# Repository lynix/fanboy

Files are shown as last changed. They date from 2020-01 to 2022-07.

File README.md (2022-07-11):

# FanBoy FanBoy Logo

Open Source PWM Fan Controller




## Summary

*FanBoy* is an Open Source DIY approach to providing a cross-platform PWM fan
controller with temperature sensor support that can easily be modified to fit
your needs.

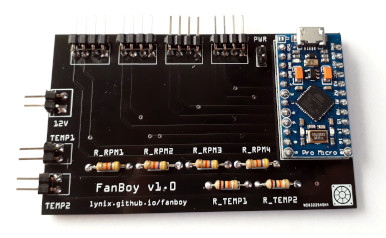
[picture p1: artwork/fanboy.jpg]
FanBoy


## Features

* **Four discrete PWM channels**  
    Supports multiple fans per channel (up to 40&thinsp;W max. total power
    draw), auto-detection for disconnected fans and RPM sensing
* **Two temperature sensor inputs**  
    Supports standard 10&thinsp;k&Omega; thermistors
* **Based on well-known Arduino platform**  
    Uses the ATmega32U4 of an Arduino Leonardo as MCU for minimal development
    overhead
* **Multiple operation modes per channel**  
    including *fixed duty*, *linear* and *target temperature*
    <sup>1</sup>
* **Persistent data storage**  
    Stores all settings as well as last operation mode CRC-protected in EEPROM
* **Simple serial protocol**  
    Comes with a simple static library for communication abstraction as well
    as a command line utility for configuration

<sup>1</sup> Planned but not implemented yet

## Components

This DIY kit consists of multiple components that are reflected as
subdirectories:

| Folder | Description | Platforms |
|:---|:---| :--- |
| [pcb](https://github.com/lynix/fanboy/tree/master/pcb) | PCB that can be manufactured very cheap via common PCB fabrication services | Linux, Win32, Mac |
| [firmware](https://github.com/lynix/fanboy/tree/master/firmware) | Firmware based on *Arduino* Core | Linux, Win32, Mac |
| [libfanboy](https://github.com/lynix/fanboy/tree/master/libfanboy) | Static C library that implements serial interface between host and *FanBoy* | Linux, Win32, Mac |
| [enclosure](https://github.com/lynix/fanboy/tree/master/enclosure) | Simple 3D printable enclosure that fits a 2.5" drive slot | - |
| [fanboycli](https://github.com/lynix/fanboy/tree/master/fanboycli) | Command line client based on `libfanboy` | Linux, Win32, Mac |

:information_source: In addition to these components there is a Qt based GUI
called [FanMan](https://github.com/lynix/fanman).

## Contributing

### Code

The code uses 4-space indentation and K&R style bracing. Usage of Arduino
libraries is kept low to keep the possibility of switching to avr-libc. Code
documentation is done inline (headers) using [Doxygen](http://www.doxygen.nl).

### Bugs / Features

Pull requests are always welcome. Feel free to report bugs or post questions
using the *issues* function on GitHub.

## License

This project is published under the terms of the *MIT License*. See the file
`LICENSE` for more information.

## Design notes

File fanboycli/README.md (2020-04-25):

# FanBoy FanBoy Logo

Open Source PWM Fan Controller




## Component: fanboycli

*fanboycli* is a command line interface application for *FanBoy* written in C
that makes use of *libfanboy*.

### Building

*fanboycli* uses [CMake](https://cmake.org) to provide a uniform cross-platform
build.

In order to build it separately (example on Linux):

```
$ cd fanboycli
$ cmake .
$ make
```

### Usage

The executable understands the following arguments:

| Argument  | Description |
|:---|:---|
| `-s` | Show current fan / sensor readings |
| `-c` | Show current configuration |
| `-f FAN`  | Select fan to control (1-4) |
| `-d DUTY` | Set selected fan to fixed duty (0-100) |
| `-m MODE` | Set fan control mode (*manual* or *linear*) |
| `-M TEMP` | Set mapped sensor no. (1-2) |
| `-l PARA` | Set linear control parameters (format see below) |
| `-L` | Load configuration from EEPROM |
| `-S` | Save current configuration to EEPROM |
| `-C` | Generate fan curves as CSV samples (duty vs. RPM) |
| `-R` | Reset FanBoy (re-initializes USB as well) |
| `-D DEV`  | Set serial interface (default value depends on platform) |
| `-V` | Show FanBoy firmware version and build timestamp |
| `-h` | Show usage help text |

Note that some argument(s) may be repeated for combination (see below).

#### Examples

Show current readings:

```
$ fanboycli -s
```

Set Fan 1 to 25% fixed duty, Fan 2 to 50% and make changes permanent:

```
$ fanboycli -f 1 -d 25 -f 2 -d 50 -S
```

Set Fan 3 to linear fan control with given parameters:

```
$ fanboycli -f 3 -l 20:19.5:80:40.5
```

### Linear Fan Control

Linear fan control makes the fan duty follow a linear curve between a given
minimum and maximum value.

Parameter format for `-l` argument: `LOW_DUTY:LOW_TEMP:HIGH_DUTY:HIGH_TEMP`

* `LOW_TEMP`: Low temperature
* `HIGH_TEMP`: High temperature
* `LOW_DUTY`: Fan duty applied when temperature <= `TEMP_LOW`
* `HIGH_DUTY`: Fan duty applied when temperature >= `TEMP_HIGH`

## License

This project is published under the terms of the *MIT License*. See the file
`LICENSE` for more information.

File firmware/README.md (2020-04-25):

# FanBoy FanBoy Logo

Open Source PWM Fan Controller




## Component: Firmware

The firmware is based on the official Arduino core. Previous attempts of using
[avr-libc](https://www.nongnu.org/avr-libc) turned out to require too much
effort as the ATmega32U4 requires a USB stack for its serial interface.
[LUFA](https://github.com/Palatis/Arduino-Lufa) may be a solution to this and
shall be evaluated.

### Building

The firmware can either be built and uploaded using the official *Arduino* IDE
or using the provided Makefile that is based on
[Arduino-Makefile](https://github.com/sudar/Arduino-Makefile).

In case of the latter, make sure you have the following installed (package names
may vary between distros): `arduino`, `arduino-mk`

The firmware can be built and uploaded as follows:

```
$ cd firmware
$ make
$ make upload
```

## License

This project is published under the terms of the *MIT License*. See the file
`LICENSE` for more information.

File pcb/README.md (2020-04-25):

# FanBoy FanBoy Logo

Open Source PWM Fan Controller




## Component: PCB

*FanBoy*'s core is the *Micro* version of an *Arduino Leonardo* (e.g.
*Paradisetronic Pro Micro* or *SparkFun Pro Micro*) carried by a very simple
PCB:

FanBoy

The board has been designed using [Fritzing](https://fritzing.org) and can be
manufactured easily via common PCB fabrication services.

**Note:** The Fritzing file makes use of the 'SparkFun Pro Micro' part created
by [Hauke Thorenz](https://github.com/htho/fritzing-parts).

### Board Description

| Connector | Description |
|:--- |:--- |
| `12V` | 12&thinsp;V DC input |
| `TEMP1`, `TEMP2` | Temperature sensor connectors |
| `FAN1-4` | PWM fan connectors |
| `R_RPM1-4` | Pull-up resistors for fan RPM signal (4.7&thinsp;k&Omega;) |
| `R_TEMP1`, `R_TEMP2` | Thermistor reference resistors (10&thinsp;k&Omega;) |
| `PWR` | Arduino power supply selector (open: USB, shorted: 12&thinsp;V DC) |

:warning: **Warning:** When using cheap *Pro Micro* clones like the ones from
Paradisetronic make sure that solder bridge `J1` is closed! You otherwise risk
frying the Arduino when connecting USB and 12V at the same time!

### Parts list

In order to build your own *FanBoy* you need the following:

* Arduino Leonardo, Micro version
* *FanBoy* PCB
* 4x 4.7&thinsp;k&Omega; resistors
* 2x 10&thinsp;k&Omega; resistors
* 4x KF2510 3+1pin fan headers
* 2x 2.54&thinsp;mm 2pin thermistor headers
* 2x 2.54&thinsp;mm 12pin headers for Arduino
* 1x 3.5&thinsp;mm DC 2pin header

## License

This project is published under the terms of the *MIT License*. See the file
`LICENSE` for more information.

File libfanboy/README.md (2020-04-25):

# FanBoy FanBoy Logo

Open Source PWM Fan Controller




## Component: libfanboy

*libfanboy* is a static library written in C that provides a cross-platform
abstraction of the binary serial protocol between *FanBoy* and host.

### Building

*libfanboy* uses [CMake](https://cmake.org) to provide a uniform cross-platform
build that can be integrated in other projects.

In order to build it separately (example on Linux):

```
$ cd libfanboy
$ cmake .
$ make
```

## License

This project is published under the terms of the *MIT License*. See the file
`LICENSE` for more information.

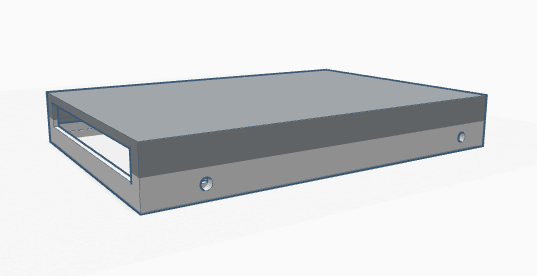
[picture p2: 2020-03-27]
enclosure/simple-enclosure.png

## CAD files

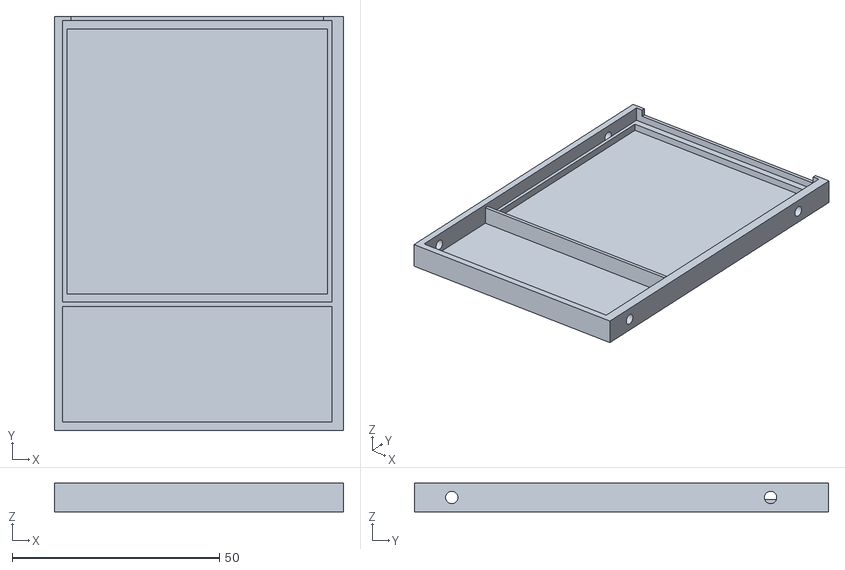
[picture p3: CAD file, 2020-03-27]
enclosure/simple-enclosure-bottom.stl
69.9 x 100.0 x 7.00

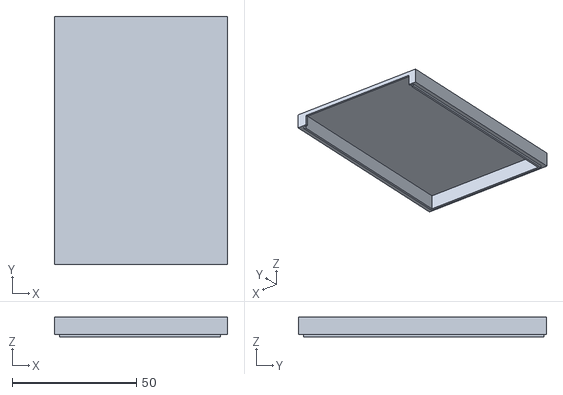
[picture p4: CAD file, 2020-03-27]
enclosure/simple-enclosure-top.stl
69.9 x 100.0 x 8.00

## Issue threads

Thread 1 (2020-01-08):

Re-layout PCB to fit one-way 2.5" enclosure

lynix, 2020-01-08:
Re-arrange the PCB layout to make it fit into a 2.5" drive enclosure. Important point is to move the connectors around so that all cables go out on one side. This allows for a (to-be-designed, 3D-printable) enclosure to be mounted in a drive bay.

Closed 2020-01-13.

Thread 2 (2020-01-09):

Design 3D printable enclosure for 2.5" bays

lynix, 2020-01-09:
Design a printable enclosure to allow mounting a *FanBoy* everywhere a 2.5" drive can be mounted.

Closed 2020-03-27.

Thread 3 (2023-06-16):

Would there be interest in updating this with a MicroFanboy?

sparky3387, 2023-06-16:
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

I made a much smaller version of this to fit with my smaller available size available to me, wondering if you would be interested in a patch to add this version to the official one? I could submit it in Fritzing format if you would like?

knghtbrd, 2024-02-09:
That looks freakin' sweet! Perfect thing to just tuck a couple extra sensors and fans into a homelab server, so I hope you offer a PR (and it gets accepted!)

As cool as this is, it doesn't solve my problem because I can't solder worth beans. Though this project is loudly suggesting to me that a facility for userland projects to provide data to hwmon/lm-sensors would be worthwhile.

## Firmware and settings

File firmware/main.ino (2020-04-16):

/* Copyright (c) 2020 Alexander Koch
 *
 * This file is part of a project that is distributed under the terms of the MIT
 * License, see file 'LICENSE'.
 */

#include <EEPROM.h>
#include <avr/wdt.h>

#include "config.h"
#include "serial.h"
#include "decl.h"

static const uint8_t pins_pwm[NUM_FAN] = PINS_PWM;
static const uint8_t pins_rpm[NUM_FAN] = PINS_RPM;
static const uint8_t pins_tmp[NUM_TEMP] = PINS_TMP;

static config_t    opts;
static status_t    status;
static version_t   version;
static char        buffer[SERIAL_BUFS];


void setup()
{
    // I/O pins
    FOREACH_FAN(i) {
        pinMode(pins_pwm[i], OUTPUT);
        pinMode(pins_rpm[i], INPUT);
    }
    FOREACH_TEMP(i)
        pinMode(pins_tmp[i], INPUT);

    // setup timer1 for 25 kHz PWM
    TCCR1A = 0;
    TCCR1B = 0;
    TCCR1C = 0;
    TCNT1  = 0;
    TCCR1A = _BV(COM1A1) | _BV(COM1B1) | _BV(COM1C1) | _BV(WGM11);
    TCCR1B = _BV(WGM13) | _BV(CS10);
    TCCR1C = _BV(WGM13) | _BV(CS10);
    ICR1   = TIMER13_TOP;

    // setup timer3 for 25 kHz PWM
    TCCR3A = 0;
    TCNT3  = 0;
    TCCR3A = _BV(COM1A1) | _BV(WGM11);
    TCCR3B = _BV(WGM13) | _BV(CS10);
    ICR3   = TIMER13_TOP;

    // setup timer4 for ~25 kHz PWM (close enough)
    TCCR4A = 0;
    TCCR4B = 4;
    TCCR4C = 0;
    TCCR4D = 0;
    PLLFRQ = (PLLFRQ & 0xCF) | 0x30;
    OCR4C  = TIMER4_TOP;
    DDRD   |= 1<<7;
    TCCR4C |= 0x09;

    // prepare firmware version record
    memset(version.version, 0, STRL);
    strncpy(version.version, VERSION, STRL-1);
    memset(version.build, 0, STRL);
    strncpy(version.build, BUILD, STRL-1);

    // scan connected fans
    fan_scan();

    // default configuration
    FOREACH_FAN(i) {
        opts.temp_unit = DEF_UNIT;
        opts.fan[i].mode = DEF_MODE;
        opts.fan[i].duty = DEF_DUTY;
        opts.fan[i].sensor = DEF_MAP;
        opts.fan[i].param.min_temp = DEF_LIN_TL;
        opts.fan[i].param.min_duty = DEF_LIN_DL;
        opts.fan[i].param.max_temp = DEF_LIN_TU;
        opts.fan[i].param.max_duty = DEF_LIN_DU;
    }

    // load configuration from EEPROM
    opts_load();

    // serial
    Serial.begin(SERIAL_BAUD);
    Serial.setTimeout(SERIAL_TIMO);
}

void loop()
{
    uint32_t now = millis();

    static uint32_t measure_next = 0;
    if (now > measure_next) {
        measure_next = now + UPDATE_INT;
        FOREACH_TEMP(i)
            status.temp[i] = get_temp(i);
        FOREACH_FAN(i) {
            if (status.fan[i].rpm != NCONN) {
                status.fan[i].rpm = get_rpm(i);
                if (opts.fan[i].mode == MODE_LINEAR)
                    set_duty_linear(i);
            }
        }
    }

    if (Serial.available())
        handle_serial();
}

uint8_t crc8(const uint8_t *data, uint16_t len)
{
    uint8_t crc = 0x00;

    while (len--) {
        uint8_t val = *data++;
        for (uint8_t i=0; i<8; i++) {
            uint8_t sum = (crc ^ val) & 0x01;
            crc >>= 1;
            if (sum)
                crc ^= 0x8C;
            val >>= 1;
        }
    }

    return crc;
}

void opts_save()
{
    uint8_t gen = (EEPROM[EEPROM_GOFFS] + 1) % EEPROM_GEN_NUM;
    EEPROM[EEPROM_GOFFS] = gen;

    eeprom_t e;
    e.magic = EEPROM_MAGIC;
    e.opts = opts;
    e.crc = crc8((const uint8_t *)&e.opts, sizeof(e.opts));

    EEPROM.put(EEPROM_OPT_OFFS(gen), e);
}

bool opts_load()
{
    uint8_t gen = EEPROM[EEPROM_GOFFS] % EEPROM_GEN_NUM;

    eeprom_t e;
    EEPROM.get(EEPROM_OPT_OFFS(gen), e);

    if (e.magic != EEPROM_MAGIC)
        return false;
    uint8_t crc = crc8((const uint8_t *)&e.opts, sizeof(e.opts));
    if (crc != e.crc)
        return false;

    opts = e.opts;
    FOREACH_FAN(i)
        if (opts.fan[i].mode == MODE_MANUAL)
            set_duty(i, opts.fan[i].duty);

    return true;
}

uint16_t get_rpm(uint8_t fan)
{
    uint16_t rpm = 0;

    FOREACH_U8(i, RPM_SNUM) {
        uint32_t time;
        FOREACH_U8(n, RPM_RETRIES) {
            time = pulseIn(pins_rpm[fan], LOW, RPM_TIMEOUT);
            if (time >= RPM_TMIN || status.fan[fan].duty == 0)
                break;
        }
        if (time >= RPM_TMIN)
            rpm += 15000000UL / time;
    }

    return rpm / RPM_SNUM;
}

uint16_t get_temp(uint8_t sensor)
{
    // Steinhart–Hart coefficients
    static const float a = 1.009249522e-03;
    static const float b = 2.378405444e-04;
    static const float c = 2.019202697e-07;

    int v0 = analogRead(pins_tmp[sensor]);
    if (!v0)
        return NCONN;

    float r2 = TMP_R * (1023.0 / (float)v0 - 1.0);
    float log_r2 = log(r2);
    float t = 1.0 / (a + b*log_r2 + c*log_r2*log_r2*log_r2);

    double temp = t - 273.15;
    if (opts.temp_unit == DEG_F)
        temp = t * 1.8 + 32.0;

    return (uint16_t)(temp * 100.0);
}

void set_duty(uint8_t fan, uint8_t value)
{
    if (value > 100)
        value = 100;
    status.fan[fan].duty = value;

    int duty = (int)value * (fan == 1 ? TIMER4_TOP : TIMER13_TOP);
    duty /= 100;

    switch (fan) {
        case 0: OCR1A = duty; break;
        case 1: OCR4D = duty; break;
        case 2: OCR3A = duty; break;
        case 3: OCR1B = duty; break;
    }
}

void set_duty_linear(uint8_t fan)
{
    double temp = status.temp[opts.fan[fan].sensor];
    double t_min = (double)opts.fan[fan].param.min_temp;
    double t_max = (double)opts.fan[fan].param.max_temp;

    uint8_t duty;
    if (temp <= t_min)
        duty = opts.fan[fan].param.min_duty;
    else if (temp >= t_max)
        duty = opts.fan[fan].param.max_duty;
    else
        duty = opts.fan[fan].param.min_duty + (temp - t_min) *
            (opts.fan[fan].param.max_duty - opts.fan[fan].param.min_duty) /
            (t_max - t_min);

    if (status.fan[fan].duty != duty)
        set_duty(fan, duty);
}

void fan_scan()
{
    FOREACH_FAN(i)
        set_duty(i, SCAN_DUTY);

    delay(SCAN_SETTLE);

    FOREACH_FAN(i) {
        FOREACH_U8(n, SCAN_TRIES) {
            status.fan[i].rpm = get_rpm(i);
            if (status.fan[i].rpm > 0)
                break;
        }
        if (status.fan[i].rpm == 0)
            status.fan[i].rpm = NCONN;
        set_duty(i, DEF_DUTY);
    }
}

void reset()
{
    wdt_enable(50);
    while (true) {};
}

void handle_serial()
{
    bool sof = false;
    while (Serial.available()) {
        int read = Serial.read();
        if (read == -1)
            continue;
        if ((uint8_t)read == SOF) {
            sof = true;
            break;
        }
    }
    if (!sof)
        return;

    int command = Serial.read();
    if (command == -1)
        return;

    size_t reply_len = 0;
    char *reply = buffer;
    switch ((cmd_t)command) {
        case CMD_VERSION:
            reply_len = sizeof(version_t);
            reply = (char *)&version;
            break;
        case CMD_STATUS:
            reply_len = sizeof(status_t);
            reply = (char *)&status;
            break;
        case CMD_CONFIG:
            reply_len = sizeof(config_t);
            reply = (char *)&opts;
            break;
        case CMD_FAN_MODE:
        {
            reply_len = 1;
            buffer[0] = RESULT_ERR;
            if (Serial.readBytes(buffer, sizeof(msg_fan_mode_t)) ==
                    sizeof(msg_fan_mode_t)) {
                msg_fan_mode_t *msg = (msg_fan_mode_t *)buffer;
                if (msg->fan < NUM_FAN && (msg->mode == MODE_MANUAL ||
                                           msg->mode == MODE_LINEAR)) {
                    opts.fan[msg->fan].mode = msg->mode;
                    if (msg->mode == MODE_MANUAL)
                        set_duty(msg->fan, opts.fan[msg->fan].duty);
                    else if (msg->mode == MODE_LINEAR)
                        set_duty_linear(msg->fan);
                    buffer[0] = RESULT_OK;
                }
            }
            break;
        }
        case CMD_FAN_DUTY:
        {
            reply_len = 1;
            buffer[0] = RESULT_ERR;
            if (Serial.readBytes(buffer, sizeof(msg_fan_duty_t)) ==
                    sizeof(msg_fan_duty_t)) {
                msg_fan_duty_t *msg = (msg_fan_duty_t *)buffer;
                if (msg->fan < NUM_FAN && msg->duty <= 100) {
                    opts.fan[msg->fan].mode = MODE_MANUAL;
                    opts.fan[msg->fan].duty = msg->duty;
                    set_duty(msg->fan, msg->duty);
                    buffer[0] = RESULT_OK;
                }
            }
            break;
        }
        case CMD_FAN_MAP:
        {
            reply_len = 1;
            buffer[0] = RESULT_ERR;
            if (Serial.readBytes(buffer, sizeof(msg_fan_map_t)) ==
                    sizeof(msg_fan_map_t)) {
                msg_fan_map_t *msg = (msg_fan_map_t *)buffer;
                if (msg->fan < NUM_FAN && msg->sensor < NUM_TEMP) {
                    buffer[0] = RESULT_OK;
                    opts.fan[msg->fan].sensor = msg->sensor;
                }
            }
            break;
        }
        case CMD_LINEAR:
        {
            reply_len = 1;
            buffer[0] = RESULT_ERR;
            if (Serial.readBytes(buffer, sizeof(msg_fan_linear_t)) ==
                    sizeof(msg_fan_linear_t)) {
                msg_fan_linear_t *msg = (msg_fan_linear_t *)buffer;
                if ( msg->fan < NUM_FAN && msg->param.min_duty <= 100 &&
                                           msg->param.max_duty <= 100) {
                    opts.fan[msg->fan].param = msg->param;
                    buffer[0] = RESULT_OK;
                }
            }
            break;
        }
        case CMD_FAN_CURVE:
            reply_len = sizeof(msg_fan_curve_t);
            fan_curve();
            break;
        case CMD_SAVE:
            reply_len = 1;
            buffer[0] = RESULT_OK;
            opts_save();
            break;
        case CMD_LOAD:
            reply_len = 1;
            buffer[0] = opts_load() ? RESULT_OK : RESULT_ERR;
            break;
        case CMD_RESET:
            reset();
            break;
        default:
            Serial.write(SOF);
            Serial.write(CMD_INVALID);
            return;
    }

    Serial.write(SOF);
    Serial.write((uint8_t)command);
    Serial.write(reply, reply_len);
}

void fan_curve()
{
    msg_fan_curve_t *data = (msg_fan_curve_t *)buffer;
    uint16_t rpm[NUM_FAN][CURVE_SMPNUM];

    for (int i=0; i<=100/CURVE_STEP; i++) {
        uint8_t duty = 100 - i * CURVE_STEP;
        FOREACH_FAN(f)
            set_duty(f, duty);
        data->points[i].duty = duty;

        delay(CURVE_SDELAY);

        FOREACH_U8(n, CURVE_SMPNUM) {
            FOREACH_FAN(f)
                rpm[f][n] = get_rpm(f);
            delay(CURVE_SMPDEL);
        }

        FOREACH_FAN(f) {
            for (int n=1; n<CURVE_SMPNUM; n++)
                rpm[f][0] += rpm[f][n];
            data->points[i].rpm[f] = rpm[f][0] / CURVE_SMPNUM;
        }
    }

    // restore manual duty
    FOREACH_FAN(i)
        if (opts.fan[i].mode == MODE_MANUAL)
            set_duty(i, opts.fan[i].duty);
}

/* vim: set ts=4 sw=4 et */

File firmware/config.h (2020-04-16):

/* Copyright (c) 2020 Alexander Koch
 *
 * This file is part of a project that is distributed under the terms of the MIT
 * License, see file 'LICENSE'.
 */

#ifndef _CONFIG_H
#define _CONFIG_H

#define NUM_FAN        4                      // No. of fans
#define NUM_TEMP       2                      // No. of sensors

#define SERIAL_BAUD    57600                  // Serial baud rate
#define SERIAL_TIMO    500                    // Serial RX timeout (ms)
#define SERIAL_BUFS    64                     // Serial buffer size (bytes)

#define PINS_PWM       { 9, 6, 5, 10 }        // Pins for fan PWM signal
#define PINS_RPM       { 8, 7, 4, 2 }         // Pins for fan RPM signal
#define PINS_TMP       { A1, A0 }             // Pins for sensors

#define TIMER13_TOP    320                    // Timer1/3 top value for 25 kHz PWM
#define TIMER4_TOP     240                    // Timer4 top value for 25 kHz PWM

#define UPDATE_INT     1000                   // Measurement interval (ms)

#define TMP_R          10000.0                // Sensor resistor (10 kOhm)

#define RPM_TIMEOUT    500000                 // RPM pulse detection timeout (us)
#define RPM_TMIN       3000                   // Minimum valid RPM pulse length (us)
#define RPM_SNUM       2                      // No. of samples for RPM measurement
#define RPM_RETRIES    2                      // No. of retries for RPM measurement

#define DEF_UNIT       DEG_C                  // Default temperature unit (C)
#define DEF_MODE       MODE_MANUAL            // Default operation mode
#define DEF_DUTY       50                     // Default fixed fan duty (%)
#define DEF_SINT       0                      // Default status interval (s)
#define DEF_MAP        0                      // Default sensor mapping
#define DEF_LIN_TL     2000                   // Default linear lower temperature
#define DEF_LIN_TU     4000                   // Default linear upper temperature
#define DEF_LIN_DL     33                     // Default linear lower duty (%)
#define DEF_LIN_DU     80                     // Default linear upper duty (%)

#define SCAN_DUTY      50                     // Fan scan duty (%)
#define SCAN_SETTLE    2000                   // Fan scan settle delay (ms)
#define SCAN_TRIES     3                      // Fan scan tries per channel

#define EEPROM_MAGIC   0xFB                   // Settings record start byte
#define EEPROM_GOFFS   15                     // Offset of generation indicator
#define EEPROM_LEN     1024                   // 1 kB EEPROM on Leonardo

#define CURVE_STEP     10                     // Curve duty step size (%)
#define CURVE_SDELAY   5000                   // Curve settle delay (ms)
#define CURVE_SMPNUM   3                      // Curve sample num per duty
#define CURVE_SMPDEL   50                     // Curve delay between samples (ms)

#ifndef VERSION
#define VERSION        "unknown"              // Fallback version string
#endif
#define BUILD		   __DATE__ " " __TIME__  // Build timestamp

#define MIN(X, Y)             (X <= Y ? X : Y)

#define FOREACH_U8(V, LIMIT)  for (uint8_t V=0; V<LIMIT; V++)
#define FOREACH_FAN(V)        FOREACH_U8(V, NUM_FAN)
#define FOREACH_TEMP(V)       FOREACH_U8(V, NUM_TEMP)

#define EEPROM_GEN_NUM        ((EEPROM_LEN - EEPROM_GOFFS-1) / sizeof(eeprom_t))
#define EEPROM_OPT_OFFS(GEN)  (EEPROM_GOFFS + 1 + GEN * sizeof(eeprom_t))

#endif

/* vim: set ts=4 sw=4 et */

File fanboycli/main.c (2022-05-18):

/* Copyright (c) 2020 Alexander Koch
 *
 * This file is part of a project that is distributed under the terms of
 * the MIT License, see file 'LICENSE'.
 */

#include <getopt.h>
#include <stdint.h>
#include <stdio.h>
#include <stdlib.h>
#include <string.h>
 
#include "libfanboy.h"

#if defined linux
const char *DEF_DEVICE = "/dev/ttyACM0";
#elif defined WIN32
const char *DEF_DEVICE = "COM1";
#endif
const char *PARAM_DELIMITER = ":";


static inline const char *peek_device(int argc, char *argv[])
{
    for (int i=argc-2; i>=0; i--)
        if (strcmp("-D", argv[i]) == 0)
            return argv[i+1];

    return DEF_DEVICE;
}

static inline void print_help()
{
    puts("Usage: fanboycli [ARGUMENT(S)]\n");

    puts(  "Device Status:");
    puts(  "  -s       Show current fan / sensor readings");
    puts(  "  -c       Show current configuration\n");

    puts(  "Fan Control:");
    printf("  -f FAN   Select fan FAN to control (1-%d)\n", NUM_FAN);
    puts(  "  -d DUTY  Set selected fan to fixed duty (0-100)");
    puts(  "  -m MODE  Set fan control mode ('manual' or 'linear')");
    printf("  -M TEMP  Set mapped sensor no. (1-%d)\n", NUM_TEMP);
    puts(  "  -l PARA  Set linear control parameters (format see below)\n");

    puts(  "Device Management:");
    puts(  "  -L       Load configuration from EEPROM");
    puts(  "  -S       Save current configuration to EEPROM");
    puts(  "  -C       Generate fan curve as CSV samples");
    puts(  "  -R       Reset FanBoy (re-initializes USB as well)\n");

    puts(  "Misc:");
    printf("  -D DEV   Set serial interface (default: '%s')\n", DEF_DEVICE);
    puts(  "  -V       Show FanBoy firmware version and build timestamp");
    puts(  "  -h       Show usage help text\n");

    puts(  "Linear parameter format: 'LOW_DUTY:LOW_TEMP:HIGH_DUTY:HIGH_TEMP'");
    puts(  "  LOW_TEMP   Low temperature");
    puts(  "  HIGH_TEMP  High temperature");
    puts(  "  LOW_DUTY   Fan duty applied when temperature <= TEMP_LOW");
    puts(  "  HIGH_DUTY  Fan duty applied when temperature >= TEMP_HIGH\n");

    puts(  "Fan duty follows a linear curve between LOW_DUTY and HIGH_DUTY.\n");

    puts(  "This version of fanboycli was built " __DATE__ " " __TIME__ "\n");
}

static inline bool get_params(char *string, linear_t *params)
{
    const char *ptr = strtok(string, PARAM_DELIMITER);
    if (ptr == NULL)
        return false;
    params->min_duty = atoi(ptr);

    ptr = strtok(NULL, PARAM_DELIMITER);
    if (ptr == NULL)
        return false;
    params->min_temp = atof(ptr) * 100.0;

    ptr = strtok(NULL, PARAM_DELIMITER);
    if (ptr == NULL)
        return false;
    params->max_duty = atoi(ptr);

    ptr = strtok(NULL, PARAM_DELIMITER);
    if (ptr == NULL)
        return false;
    params->max_temp = atof(ptr) * 100.0;

    if (params->min_duty > 100 || params->max_duty > 100 ||
            params->min_temp > 10000 || params->max_temp > 10000)
        return false;

    return true;
}

static inline void print_config(const fb_config_t *config)
{
    puts("FanBoy config:");

    char unit = config->temp_unit == DEG_C ? 'C' : 'F';
    printf("  Temperature unit: %c\n", unit);

    for (int i=0; i<NUM_FAN; i++) {
        printf("  Fan %d:\n", i+1);
        printf("    Mode:         %s\n", config->fan[i].mode == MODE_MANUAL ?
               "manual" : "linear");
        printf("    Manual duty:  %02d%%\n", config->fan[i].duty);
        printf("    Sensor:       %d\n", config->fan[i].sensor+1);
        puts("    Linear params:");
        printf("      Low:   %02d%% @ %.2f %c\n", config->fan[i].param.min_duty,
               (double)config->fan[i].param.min_temp/100.0, unit);
        printf("      High:  %02d%% @ %.2f %c\n", config->fan[i].param.max_duty,
               (double)config->fan[i].param.max_temp/100.0, unit);
    }
}

static inline void print_status(const fb_status_t *status)
{
    puts("FanBoy status:");

    for (int i=0; i<NUM_FAN; i++) {
        printf("  Fan %d: ", i+1);
        if (status->fan[i].rpm != NCONN)
            printf("%d%% @ %d rpm\n", status->fan[i].duty, status->fan[i].rpm);
        else
            puts("disconnected");
    }
    for (int i=0; i<NUM_TEMP; i++) {
        printf("  Temp %d: ", i+1);
        if (status->temp[i] != NCONN)
            printf("%.2f\n", (double)status->temp[i] / 100.0);
        else
            puts("disconnected");
    }
}

int main(int argc, char *argv[])
{
    const char *device = peek_device(argc, argv);

    if (!fb_init(device)) {
        fprintf(stderr, "Failed to connect to '%s': %s\n", device, fb_error());
        return 1;
    }
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

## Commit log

2020-01-08 firmware: Add sensor -> fan mapping
    This is required for temperature-based fan control.
2020-01-08 firmware: Change numbering scheme to match PCB
    Make fans and sensors be counted by one (instead of zero) in all places
    involving (possibly human) serial interaction to match names printed on PCB.
    Keep internal numbering scheme for array access.
2020-01-08 firmware: Introduce serial output macros
    Introduce macros wrapping snprintf() and Serial.println() in a uniform
    interface.
2020-01-08 firmware: Replace left-over sprintf() calls by snprintf()
    Replace potentially unsafe calls to sprintf() by snprintf() to ensure serial
    buffer is not overflown.
    [main.ino]
2020-01-08 firmware: Rename opts_t members (trivial)
    Rename opts_t members to allow for better grouping (more members to come for
    temperature-based control algorithms).
2020-01-09 firmware: Implement linear temperature-based control
    Implement 'linear' operation mode, controlling fan duty by applying a
    parameterized linear duty curve of the following form:
    Fan Duty
    ^
    |
    d_max - ------
    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
2020-01-09 Makefile: Allow ARDUINO_PORT to be overwritten
    Allow users to change serial device for firmware upload when calling Make, e.g.
    $ make ARDUINO_PORT=/dev/ttyACM1 upload
2020-01-13 pcb: Re-layout
    Re-layout PCB to fit inside 2.5" drive enclosures with all cables coming out on
    one side. This shall allow mounting it everywhere an SSD can be mounted.
    While at it, make power circuit use 32 mil wires to increase maximum amperage.
    According to IPC-2221 total power draw should be arround 2.4-2.9 A (depending
    on temperature increase).
    This does not induce any change regarding firmware.
    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
    [fanboy.fzz]
2020-02-06 firmware: Improve RPM measurement
    - Consider pulse lengths < 3000 us invalid
    - Retry on pulseIn() timeout (except fan is set to 0% duty)
    - Smoothe values by simple arithmetic mean
2020-02-06 firmware: Remove UTF-8 character from status output
    Keep serial output ASCII compliant by removing accidentially inserted UTF-8 code
    point (degree symbol).
2020-02-06 firmware: Implement fan mode switching
    Finalize 'linear' operation mode implementation by adding 'mode' command for
    switching (and displaying) fan mode. Ensure that setting a manual duty makes the
    fan switch to 'manual' mode automatically.
2020-02-13 firmware: Fix casing in fixed duty message (trivial)
    [main.ino]
2020-02-13 firmware: Improve linear param command
    Show fan no. when printing linear parameters. Required for parsers to match
    corresponding fan.
2020-02-14 pcb: Enlarge to avoid having fan connectors stand out
    Enlarge PCB to cover fan connectors on left edge. While at it, fix some flipped
    labels.
    [fanboy.fzz]
2020-02-19 firmware: Unify fan mapping messages
    Make output for fan mappings equal, no matter whether mapping has been changed
    or queried.
2020-03-25 firmware: Print linear parameters on change
    Make cmd_linear() print updated parameters on change. Required as feedback for
    clients (e.g. GUI).
2020-03-27 Add simple printable enclosure
    Add a simple 3D printable enclosure that allows for mounting the FanBoy inside a
    2.5" drive bay.
    - Dimensions: 100 x 69.85 x 15 mm
    - Use short screws for mounting
    This closes #2.
    [simple-enclosure-bottom.stl, simple-enclosure-top.stl]
2020-03-27 pcb: Re-layout to allow for thinner enclosure
    Re-position most components to allow for better cable routing. This shall enable
    decreasing the height of enclosures to be slim enough to fit standard 2.5" drive
    bays.
    While at it, increase wire width for power circuit to 48 mil. This should be
    enough to safely power common PC water cooling pumps.
    [fanboy.fzz]
2020-04-09 firmware: Add 'reset' command
    Introduce 'reset' command that re-initializes the device.
    Note: as the ATmega32u4 does USB-to-serial on its own, resetting the chip also
    re-initializes USB and therefore makes the USB TTY disappear for a short period
    of time.
    This has the disadvantage of disconnecting serial clients but the benefit of
    knocking a blocked USB stack loose along the way.
    [main.ino]
2020-04-16 firmware: Switch serial to binary protocol
    Implement a simple binary protocol for serial communication with host. This
    makes the firmware for the Arduino much simpler and even a bit faster as all
    string processing can be omitted.
2022-05-18 fanboycli: Fix off-by-one in sensor mapping
    [main.c]

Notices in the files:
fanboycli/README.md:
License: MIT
